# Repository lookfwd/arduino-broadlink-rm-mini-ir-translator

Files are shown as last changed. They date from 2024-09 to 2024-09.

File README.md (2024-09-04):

# Arduino Broadlink RM Mini IR Translator

## Summary
An Arduino project that provides full control over the Broadlink WiFi RM Mini 3.
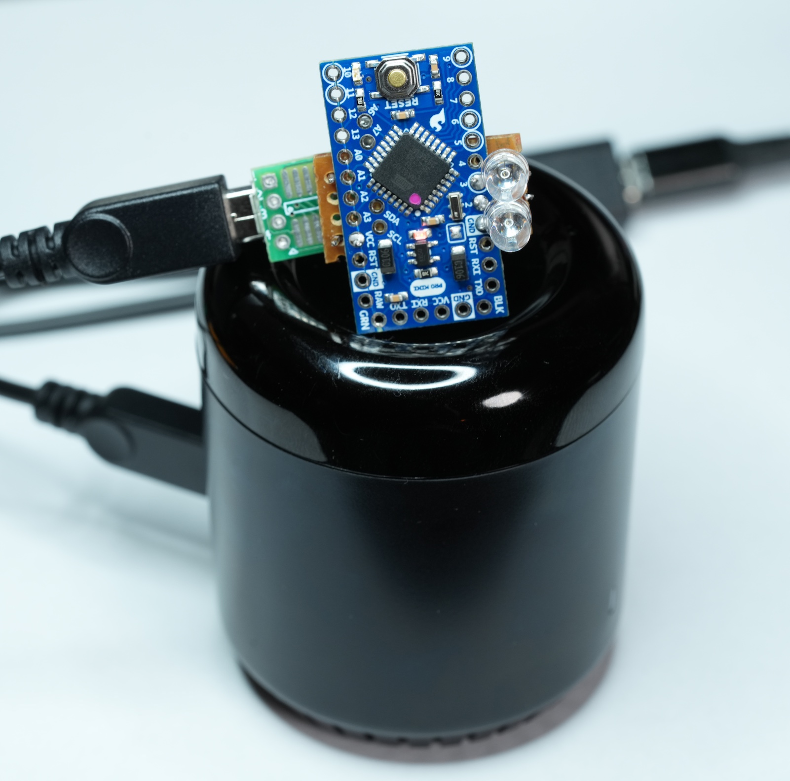
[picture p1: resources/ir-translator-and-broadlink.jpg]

## Back Story
A couple of months ago, I bought [a small disco ball](https://www.amazon.com/gp/product/B0D2SVSR26/) for my child's room.

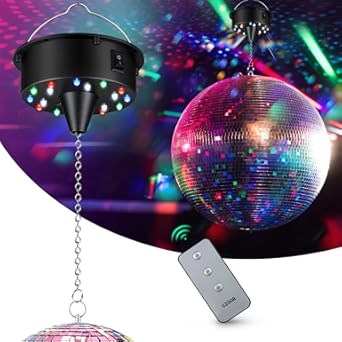
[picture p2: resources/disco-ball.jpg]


It's decent, and the battery life is satisfactory, but most importantly, my toddler loves it! Since we knew we wanted to keep it, I decided to integrate it with Google Home so I could control it with voice commands, e.g., by saying, "Hey Google, turn off the disco ball in 20 minutes." To achieve this, I purchased one of my favorite devices, the [Broadlink WiFi Smart Home Hub RM Mini 3](https://www.amazon.com/dp/B07K2DHXB6). However, after a quick setup, I was disappointed. To turn the disco ball off, you have to press a button three times quickly. This is a bit annoying, and the Hub RM Mini 3 didn’t seem to support it. I confirmed with their support that:

> If your physical remote requires pressing a button three times to send a different IR code, this cannot be supported by the BroadLink RM device. However, you can try creating three separate buttons for your physical remote and learn each press. You can then try controlling it and see if it works. Long press actions are also not supported.

## Solution

So, I built an Arduino circuit that acts as a middleman. It reads the Broadlink RM Mini 3 IR signals, and when it detects a command, it translates it to more complex disco ball remote control actions, like pressing a button three times.

Encoding and decoding IR commands has been around for over 30 years, so *there are better projects* out there, like [IRremote](https://github.com/Arduino-IRremote/Arduino-IRremote), used by [this excellent example](https://github.com/mattcuk/IRtranslator). If you’re starting from scratch, you might want to use their code instead of mine. One thing they might not have is powering down the processor when it’s idle. In any case, I reinvented the wheel because I enjoy the process, and I got to use tools I had on hand.

Here’s the sketch:

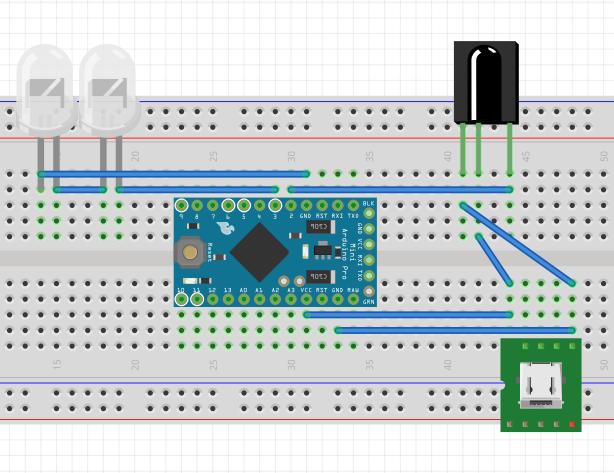
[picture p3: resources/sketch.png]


## Components

The components I used are:

* I started with an Arduino Uno for quick development but eventually switched to a SparkFun Arduino Pro Mini - 5V, as it’s smaller and I won’t need to change the software often.
* I used a [Micro USB Type B Receptacle](https://www.mouser.com/ProductDetail/649-10118192-0001LF) to get 5V power via USB. [This splitter](https://www.amazon.com/dp/B00ISLNSH0) allowed me to power both the Broadlink RM Mini 3 and my Arduino with the same cable.
* I used a [VS1838B](https://www.amazon.com/dp/B06XYNDRGF) to receive IR and decode the 38kHz carrier. The signal is fed directly to Arduino's Pin 2, which also triggers an interrupt upon logic level change and wakes the Arduino from sleep.
* I used two [TS-242 IR LEDs](https://tinkersphere.com/standard-leds/242-ir-led-25-pack.html) because I had them available and knew their specs, including the 2.4V - 2.6V forward voltage. This was important because I burned out an IR LED, which wasted some time figuring out. I’d rather avoid burnt LEDs!

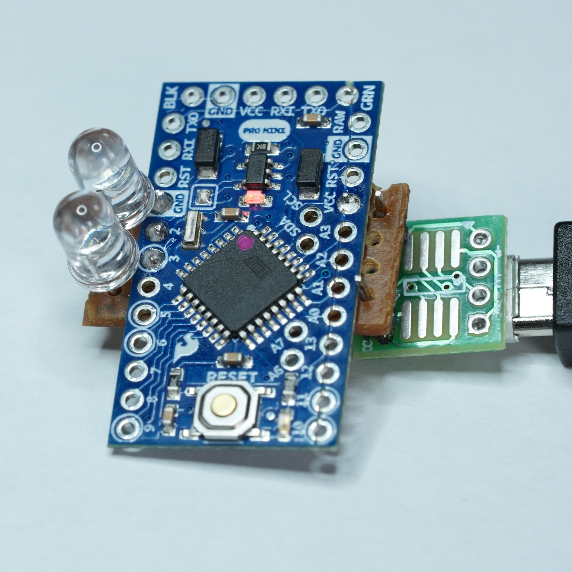
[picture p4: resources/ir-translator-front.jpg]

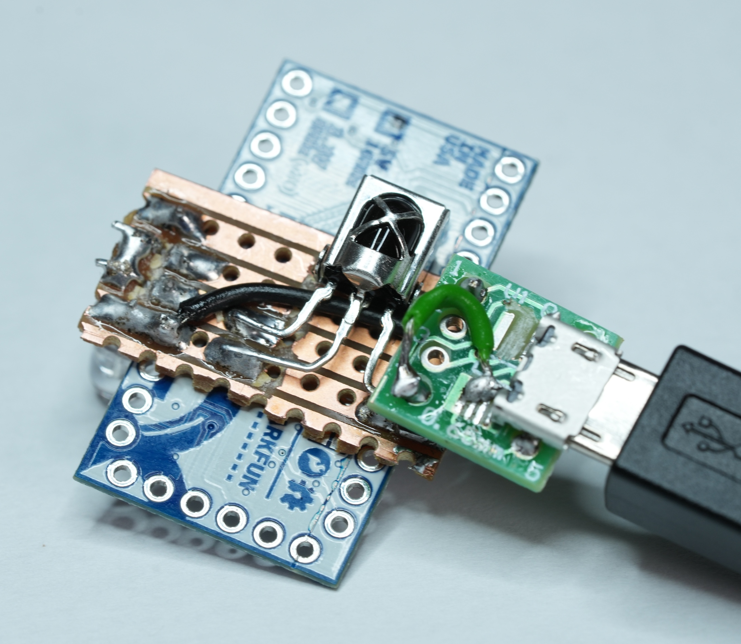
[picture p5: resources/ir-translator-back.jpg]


## Development
I made the Broadlink RM Mini 3 pretend it’s an LG 32LE4500. I chose that protocol because it’s short and very similar, if not identical, to the one the disco ball uses.

I used a [DSLogic U3Pro16 logic analyzer](https://www.amazon.com/dp/B08C2LCBGL) to decode the IR signals from the remote control. I bought this analyzer specifically for this project, though I suspect that much of the motivation behind this project was an excuse to play with it before using it on more complex projects.

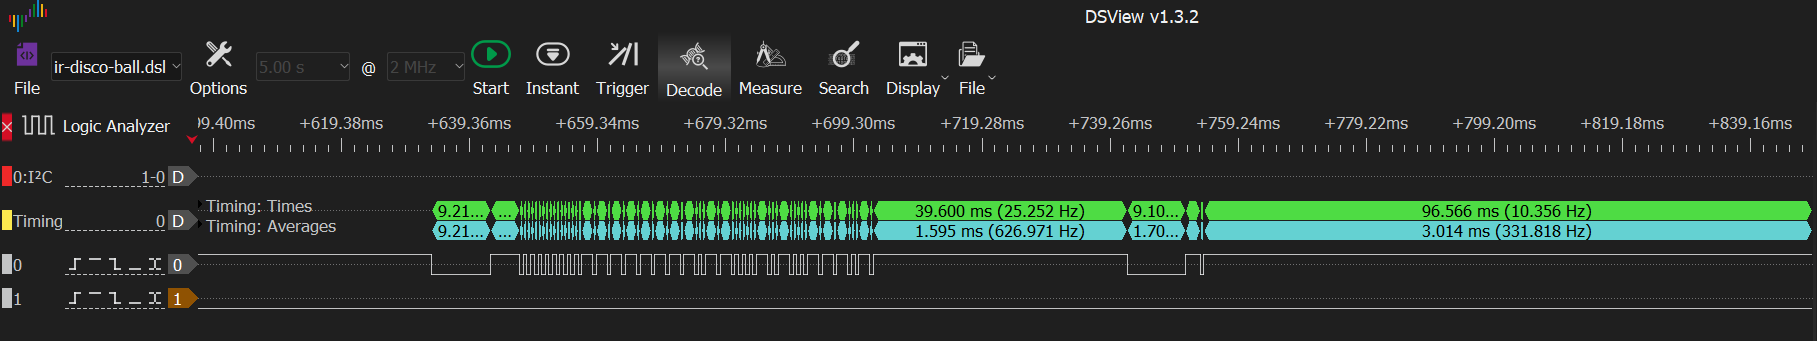
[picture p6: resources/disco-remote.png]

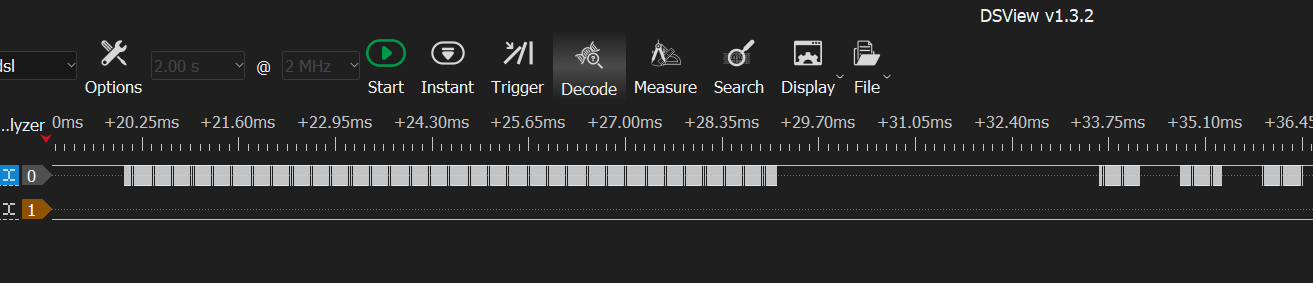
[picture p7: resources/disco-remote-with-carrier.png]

I also used a [Nordic Semiconductor Power Profiler Kit II](https://www.digikey.com/en/products/detail/nordic-semiconductor-asa/NRF-PPK2/13557476) to measure power consumption. I made a small code modification to enable power-saving mode when the system is idle. The VS1838B consumes 0.4 mA according to its datasheet (I measured 220µA when idle and 350µA when active), so this won’t be an ultra-low-power design, but I’m happy to write a few lines of code to make it greener. The idle mode reduces the current from 14 mA to 8 mA. Deeper sleep modes like the standby mode were promising, but didn't work out because they messed with accuracy of time measurement between interrupts.

VS1838B Power Consumption:
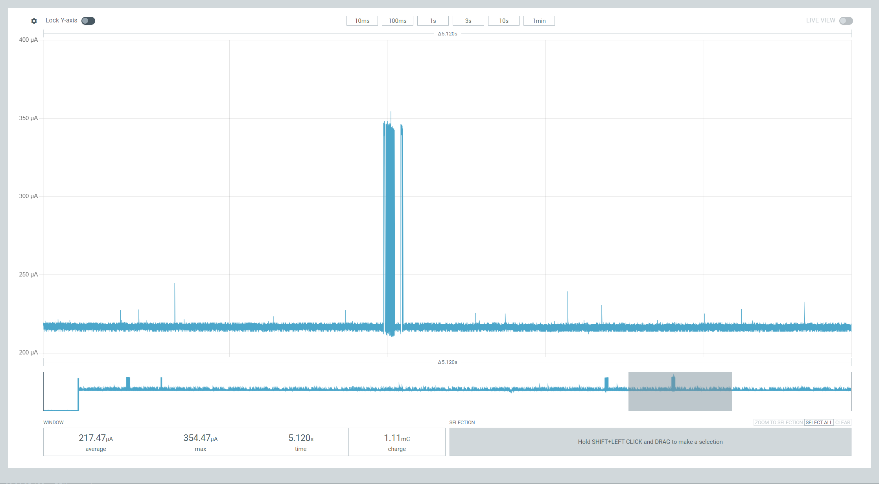
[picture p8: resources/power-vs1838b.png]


System Power Consumption - No Power Down Mode:
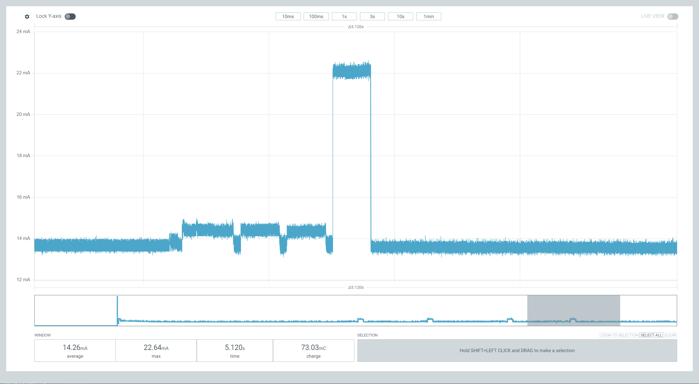
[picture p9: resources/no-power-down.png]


System Power Consumption - With Power Down Mode:
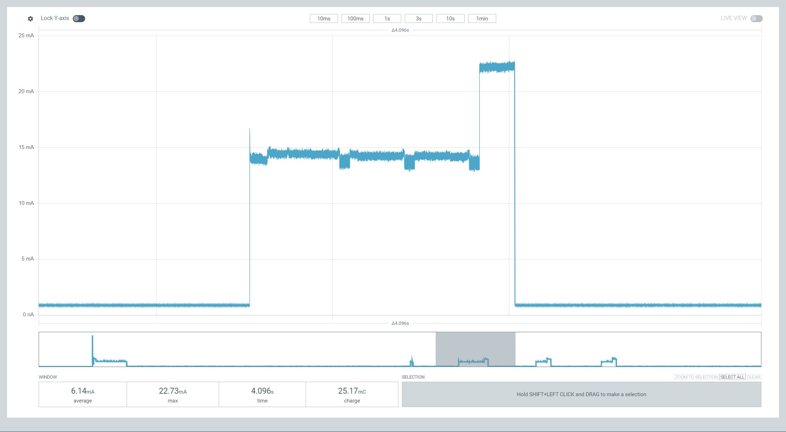
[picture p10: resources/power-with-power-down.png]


At the end I also removed the Arduino Pro Mini power led - in the spirit of lowering power. 

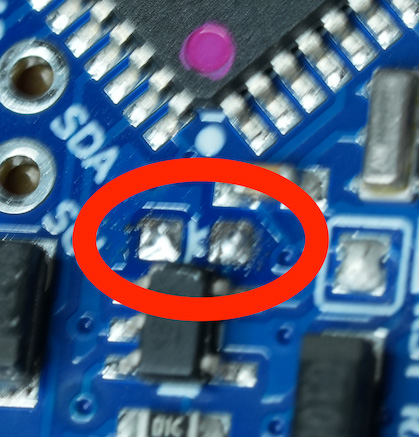
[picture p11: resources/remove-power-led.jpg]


I also had to make a quick fix to the tone Arduino library with this PR [Quick Fix of overflow for larger toggle_count values by lookfwd · Pull Request #565](https://github.com/arduino/ArduinoCore-avr/pull/565). I didn't expect that I would hit an Arduino core bug that quickly, but here we are.

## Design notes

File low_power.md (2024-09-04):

# Low Power

Did the following experiment with an Arduino Uno:

```
// Without SLEEP_MODE_*       at 1kHz: 42mA max: 43mA - Doesn't go up with frequency
// With    SLEEP_MODE_IDLE    at 1kHz: 35mA max: 38mA - Goes up with frequency
// With    SLEEP_MODE_STANDBY at 1kHz: 30mA max: 34mA - Goes up with frequency
#include <avr/sleep.h>

// Should support ISR on change
#define PIN_IR_RECEIVER 2
#define PIN_IR_LED 3

void setup() {
  pinMode(PIN_IR_RECEIVER, INPUT_PULLUP);
  pinMode(PIN_IR_LED, OUTPUT);

  digitalWrite(PIN_IR_LED, LOW);

  attachInterrupt(digitalPinToInterrupt(PIN_IR_RECEIVER), pinChangeISR, CHANGE);

  set_sleep_mode(SLEEP_MODE_STANDBY);
  sleep_enable();
}

void loop() {
  sleep_mode();
  //delay(1000);
}

void pinChangeISR() {
  int val = digitalRead(PIN_IR_RECEIVER);
  digitalWrite(PIN_IR_LED, val);
}
```

In every case I saw the output mirror the input with 10-11uS of delay. This shows that `CHANGE` interrupt works even with `SLEEP_MODE_STANDBY`. The same code with `SLEEP_MODE_PWR_DOWN` has 1ms+ delays i.e. doesn't work as expected from the manual.

Tried the main timer/pin ISR mechanism on Arduino Uno and Arduino Mini Pro:

```
#include <avr/sleep.h>

// Should support ISR on change
#define PIN_IR_RECEIVER 2
#define PIN_IR_LED 3

void setup() {
  Serial.begin(115200);
  delay(300);

  pinMode(PIN_IR_RECEIVER, INPUT_PULLUP);
  pinMode(PIN_IR_LED, OUTPUT);

  digitalWrite(PIN_IR_LED, LOW);

  attachInterrupt(digitalPinToInterrupt(PIN_IR_RECEIVER), pinChangeISR, CHANGE);

  noInterrupts();
  TCCR1A = 0;              // Set Timer1 to Normal mode
  TCCR1B = 0;              // Set Timer1 to Normal mode
  TCNT1 = 0;               // Initialize counter to 0
  TCCR1B |= (1 << CS11);   // Set prescaler to 8 (1 tick = 0.5 µs)
  TIMSK1 |= (1 << TOIE1);  // Enable Timer1 overflow interrupt
  interrupts();

  set_sleep_mode(SLEEP_MODE_STANDBY);
  sleep_enable();
}

volatile bool timer1on = false;

volatile int duration = 0;
int cnt = 0;

void enableTimer1() {
  TCNT1 = 0;               // Initialize counter to 0
  TCCR1B |= (1 << CS11);   // Set prescaler to 8 (1 tick = 0.5 µs)
  TIMSK1 |= (1 << TOIE1);  // Enable Timer1 overflow interrupt
  timer1on = true;
}

void disableTimer1() {
  TIMSK1 &= ~(1 << TOIE1);  // Disable Timer1 overflow interrupt
  TCCR1B &= ~(1 << CS11);   // Set prescaler to 0 (No Input)
  
  TCNT1 = 0;                // Initialize counter to 0
  timer1on = false;
}

void loop() {
  if (++cnt > 100) {
    // At 4khz 125uS pulse => with prescaler of 8 => 0.5us Timer tick
    // duration should often be 250.

    float half_period_duration_us = (float)duration * 0.5;
    Serial.print(half_period_duration_us);
    Serial.print(" ");
    Serial.println(1. / (2 * 0.000001 * half_period_duration_us));
    cnt = 0;
  }
  delay(1);

  if (!timer1on) {
    Serial.println("Sleep");
    delay(1);
    sleep_mode();
  }
}

ISR(TIMER1_OVF_vect) {
  disableTimer1();
}

void pinChangeISR() {
  int val = digitalRead(PIN_IR_RECEIVER);
  digitalWrite(PIN_IR_LED, val);

  if (!timer1on) {
    enableTimer1();
  }

  duration = TCNT1;

  TCNT1 = 0;
}
```

It all works as expected, confirming that the timer counts find despite the occassional power downs. I used a 40Hz square to make sure measurments are ok. Then I switched to a 1% duty cycle 10Hz pulse that allows the timer to overflow and the processor enter the sleep mode. Still, it measures the pulse length correctly:

```
973.00 513.87
Sleep
Sleep
Sleep
973.00 513.87
...
```

With this process I confirmed that the Arduino ISRs and timers work fine when in sleep mode. This means that if the Arduino behaves in an unexpected way, it's due to race conditions. I've implemented a double-buffer solution to mitigate such race conditions.

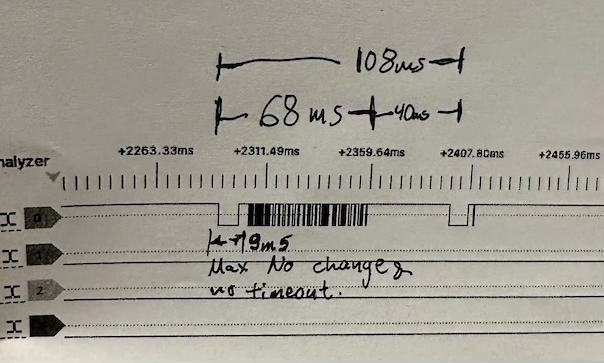
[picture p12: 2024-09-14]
resources/timing-details.png

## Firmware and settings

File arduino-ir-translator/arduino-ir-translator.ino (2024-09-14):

#include <avr/sleep.h>
#include <avr/wdt.h>
#include <avr/interrupt.h>

#define BUFFER_LIMIT 200

// Solution to (2^16 - TIMEOUT_OFFSET) * 0.5uS = 12ms
// We want timeout at 12ms from the last pulse because
// that's when we know for sure it's the end of a packet
#define TIMEOUT_OFFSET 41536

struct Frame {
  unsigned long times[BUFFER_LIMIT];
  int len;
  void reset() {
    len = 0;
  }
  Frame() {
    reset();
  }
};

Frame b1, b2;  // Double buffer scheme
Frame* read;   // This can be NULL or a buffer for the consumer (loop) to process
Frame* write;  // This always points to a write buffer for producers (ISRs)

bool timer1on = false;

// Should support ISR on change
#define PIN_IR_RECEIVER 2
#define PIN_IR_LED 3

void debugPrint(const Frame& frame) {
  Serial.print("code (");
  Serial.print(frame.len);
  Serial.print("): ");
  for (int i = 0; i < frame.len; ++i) {
    Serial.print((float)frame.times[i] / 2000);
    Serial.print(" ");
  }
  Serial.println();
}

// One ms is 2k * .5us which is the timer clock
#define MS_TO_TICK(x) ((int)(x * 2000))
#define TONE_OVERHEAD_US 360

void send(int* decoded) {
  tone(PIN_IR_LED, 38000);  // Start
  delay(9);
  noTone(PIN_IR_LED);

  delayMicroseconds(4500);

  for (int i = 0; i < 32; ++i) {
    tone(PIN_IR_LED, 38000);
    delayMicroseconds(610 - TONE_OVERHEAD_US);
    noTone(PIN_IR_LED);

    if (decoded[i >> 3] & (1 << (7 - (i & 7)))) {
      delayMicroseconds(1670);
    } else {
      delayMicroseconds(520);
    }
  }

  // Stop
  tone(PIN_IR_LED, 38000);
  delayMicroseconds(620 - TONE_OVERHEAD_US);
  noTone(PIN_IR_LED);
}

void sendOn() {
  int decoded[] = { 0, 255, 98, 157 };
  send(decoded);
}

void send6h() {
  int decoded[] = { 0, 255, 168, 87 };
  send(decoded);
}

void sendOffOnce() {
  int decoded[] = { 0, 255, 24, 231 };
  send(decoded);
}

void sendOffTwice() {
  int decoded[] = { 0, 255, 24, 231 };
  send(decoded);
  delay(300);
  send(decoded);
}

void sendOffThreeTimes() {
  int decoded[] = { 0, 255, 24, 231 };
  send(decoded);
  delay(300);
  send(decoded);
  delay(300);
  send(decoded);
}

int decodeDisco(const Frame& frame, int* decoded) {
  // Button ON:  decoded: 0 255 98 157
  // Button 6H:  decoded: 0 255 168 87
  // Button OFF: decoded: 0 255 24 231

  // All times milliseconds
  // times[0]; // This is random - time of first pulse after last timeout
  // times[1,2] // 9.14 4.47 low and high-edge

  // 8 Bits of zero
  // 0.61 0.52 | 0.61 0.52 | 0.61 0.52 | 0.61 0.52 | 0.61 0.52 | 0.61 0.52 | 0.61 0.52 | 0.61 0.52
  // 8 bits of one
  // 0.61 1.67 | 0.61 1.67 | 0.61 1.67 | 0.61 1.67 | 0.61 1.67 | 0.61 1.67 | 0.61 1.67 | 0.61 1.67
  // Actual code and its complement:
  // 0.61 0.52 | 0.61 1.67 | 0.61 1.67 | 0.61 0.52 | 0.61 0.52 | 0.61 0.52 | 0.61 1.67 | 0.61 0.52
  // 0.61 1.67 | 0.61 0.52 | 0.61 0.52 | 0.61 1.67 | 0.61 1.67 | 0.61 1.67 | 0.61 0.52 | 0.61 1.67

  // 0.59 // Last raising:

  if (frame.len != 68) {
    return -1;
  }

  const unsigned long* times = frame.times;

  // Start
  if (!(times[1] > MS_TO_TICK(7.5) && times[1] < MS_TO_TICK(10))) {
    return -2;
  }
  if (!(times[2] > MS_TO_TICK(3.5) && times[2] < MS_TO_TICK(5))) {
    return -3;
  }

  for (int i = 0; i < 32; ++i) {
    int high = times[i * 2 + 3];
    int low = times[i * 2 + 4];

    bool zero = (high > MS_TO_TICK(0.5) && high < MS_TO_TICK(0.8)) && (low > MS_TO_TICK(0.5) && low < MS_TO_TICK(0.8));
    bool one = (high > MS_TO_TICK(0.5) && high < MS_TO_TICK(0.8)) && (low > MS_TO_TICK(1.5) && low < MS_TO_TICK(1.8));
    if (!(one ^ zero)) {
      return -4;
    }
    decoded[i >> 3] <<= 1;
    if (one) {
      ++decoded[i >> 3];
    }
  }

  if ((decoded[0] + decoded[1]) != 255) {
    return -5;
  }

  if ((decoded[2] + decoded[3]) != 255) {
    return -6;
  }

  return 0;
}

void decodeDiscoAndPrint(const Frame& frame) {
  int decoded[4] = { 0, 0, 0, 0 };
  int rc = decodeDisco(frame, decoded);
  if (rc == 0) {
    Serial.print("decoded: ");
    for (int i = 0; i < 4; ++i) {
      Serial.print(decoded[i]);
      Serial.print(" ");
    }
    Serial.println();
  }
}


int decodeLg(const Frame& frame, int* decoded) {
  // key 1: decoded: 32 223 136 119
  // key 2: decoded: 32 223 72 183
  // key 3: decoded: 32 223 40 215
  // key 4: decoded: 32 223 200 55
  // key 5: decoded: 32 223 168 87

  if (frame.len != 68) {
    return -1;
  }

  const unsigned long* times = frame.times;

  // Start
  if (!(times[1] > MS_TO_TICK(7.5) && times[1] < MS_TO_TICK(10))) {
    return -2;
  }
  if (!(times[2] > MS_TO_TICK(3.5) && times[2] < MS_TO_TICK(5))) {
    return -3;
  }

  for (int i = 0; i < 32; ++i) {
    int high = times[i * 2 + 3];
    int low = times[i * 2 + 4];

    bool zero = (high > MS_TO_TICK(0.38) && high < MS_TO_TICK(0.75)) && (low > MS_TO_TICK(0.25) && low < MS_TO_TICK(0.75));
    bool one = (high > MS_TO_TICK(0.38) && high < MS_TO_TICK(0.75)) && (low > MS_TO_TICK(1.25) && low < MS_TO_TICK(1.75));
    if (!(one ^ zero)) {
      Serial.print("Error in digit: ");
      Serial.print(i);
      Serial.print(": ");
      Serial.print((float)(high * 2) / 1000);
      Serial.print(" ");
      Serial.println((float)(low * 2) / 1000);
      return -4;
    }
    decoded[i >> 3] <<= 1;
    if (one) {
      ++decoded[i >> 3];
    }
  }

  if ((decoded[0] + decoded[1]) != 255) {
    return -5;
  }

  if ((decoded[2] + decoded[3]) != 255) {
    return -6;
  }

  return 0;
}

// Remote Control: LG 32LE4500
void decodeLGAndPrint(const Frame& frame) {
  int decoded[4] = { 0, 0, 0, 0 };
  int rc = decodeLg(frame, decoded);
  if (rc == 0) {
    Serial.print("decoded: ");
    for (int i = 0; i < 4; ++i) {
      Serial.print(decoded[i]);
      Serial.print(" ");
    }
    Serial.println();
  } else {
    debugPrint(frame);
  }
}

void enableTimer1() {
  TCNT1 = TIMEOUT_OFFSET;  // Initialize counter to 0
  TCCR1B |= (1 << CS11);   // Set prescaler to 8 (1 tick = 0.5 µs)
  TIMSK1 |= (1 << TOIE1);  // Enable Timer1 overflow interrupt
  timer1on = true;
}

void disableTimer1() {
  TIMSK1 &= ~(1 << TOIE1);  // Disable Timer1 overflow interrupt
  TCCR1B &= ~(1 << CS11);   // Set prescaler to 0 (No Input)

  TCNT1 = TIMEOUT_OFFSET;  // Initialize counter to 0
  timer1on = false;
}

void setup() {
  Serial.begin(115200);
  delay(300);

  pinMode(PIN_IR_RECEIVER, INPUT_PULLUP);
  pinMode(PIN_IR_LED, OUTPUT);
  pinMode(LED_BUILTIN, OUTPUT);
  digitalWrite(PIN_IR_LED, LOW);
  digitalWrite(LED_BUILTIN, LOW);

  read = NULL;
  write = &b1;
  write->reset();

  noInterrupts();
  TCCR1A = 0;  // Set Timer1 to Normal mode
  TCCR1B = 0;  // Set Timer1 to Normal mode
  // enableTimer1(); // Only enable on pin change
  interrupts();

  attachInterrupt(digitalPinToInterrupt(PIN_IR_RECEIVER), pinChangeISR, CHANGE);

  // set_sleep_mode(SLEEP_MODE_IDLE);
  // set_sleep_mode(SLEEP_MODE_PWR_SAVE);
  set_sleep_mode(SLEEP_MODE_STANDBY);
  // set_sleep_mode(SLEEP_MODE_PWR_DOWN);

  // sendOn();
  // send6h();
  // sendOffOnce();
  // sendOffTwice();
  // sendOffThreeTimes();
}

void processRead(const Frame& frame) {
  //decodeDiscoAndPrint();
  //debugPrint();
  //decodeLGAndPrint();
  int decoded[4] = { 0, 0, 0, 0 };
  int rc = decodeLg(frame, decoded);
  if (rc != 0) {
    return;
  }

  const int unit = decoded[0];
  if (unit != 32) {
    return;
  }

  const int command = decoded[2];
  if (command <= 0) {
    return;
  }

  // Let the old command settle down. That's
  // 500 ms to settle on top of 200ms so that
  // we get rid of up to two repeats and their
  // timeouts
  delay(700);

  switch (command) {
    case 136:  // Key 1
      Serial.println("Sending on");
      sendOn();
      break;
    case 72:  // Key 2
      Serial.println("Sending 6h");
      send6h();
      break;
    case 40:  // Key 3
      Serial.println("Sending off once");
      sendOffOnce();
      break;
    case 200:  // Key 4
      Serial.println("Sending off twice");
      sendOffTwice();
      break;
    case 168:  // Key 5
      Serial.println("Sending off three times");
      sendOffThreeTimes();
      break;
    default:
      return;  // Don't blink the led
  }

  digitalWrite(LED_BUILTIN, HIGH);
  delay(200);
  digitalWrite(LED_BUILTIN, LOW);
}

void loop() {
  Frame* frame = NULL;
  noInterrupts();
  if (read) {
    frame = read;
    read = NULL;
  }
  interrupts();

  if (frame) {
    processRead(*frame);
    frame->reset();
  }

  // Avoid test race condition - see:
  // https://www.nongnu.org/avr-libc/user-manual/group__avr__sleep.html
  cli();
  if (!timer1on && !read) {
    sleep_enable();
    sei();
    sleep_cpu();
    sleep_disable();
  }
  sei();
}

// Timeout. On next wake up do `timout()`
ISR(TIMER1_OVF_vect) {

  // No need to disable interrupts while we're in the ISR
  if (!read) {
    read = write;
    write = (write == &b1) ? &b2 : &b1;
  }  // implicitly else - discard this write buffer
  write->reset();

  TCNT1 = TIMEOUT_OFFSET;
  disableTimer1();
}

// ISR. Mark time since last pulse
void pinChangeISR() {
  if (!timer1on) {
    enableTimer1();
  }
  if (write->len < BUFFER_LIMIT) {
    write->times[write->len++] = TCNT1 - TIMEOUT_OFFSET;
  }
  TCNT1 = TIMEOUT_OFFSET;
}
